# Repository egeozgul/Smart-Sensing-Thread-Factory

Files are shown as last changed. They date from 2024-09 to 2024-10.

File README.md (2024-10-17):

# Smart-Sensing-Thread-Factory

<p align="center">
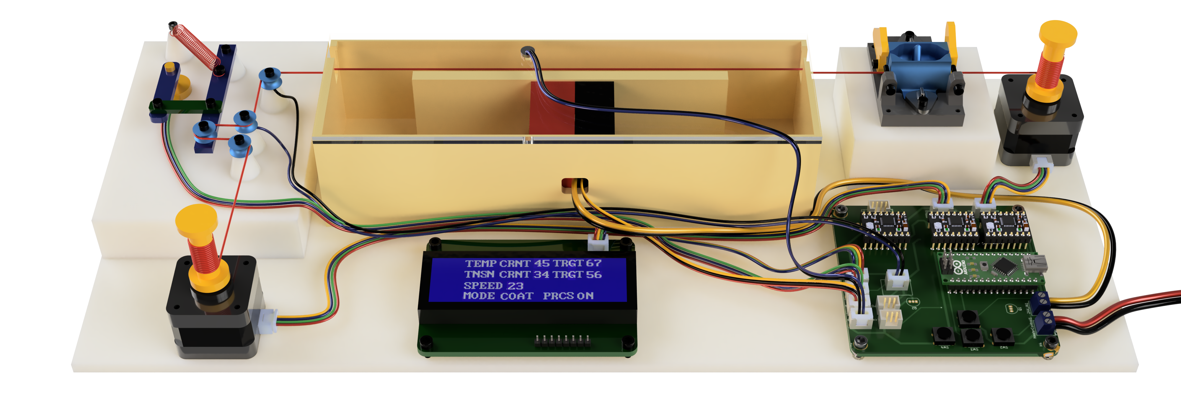
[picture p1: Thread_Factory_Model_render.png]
  
</p>

## Overview

This is a device built for Tufts NanoLab lab to assist the sensor development and wearable electronics research projects. This device automates the smart thread sensor production process using a combination of sensors and actuators.
This project is published at MDPI: [Publication Link](https://www.mdpi.com/2072-666X/15/10/1239) 

## Contents

- **PCB_productionFiles**: This folder contains all the necessary PCB design files required for creating the electronic boards that drive the system. The PCBs connect the microcontroller to the sensors and motors, enabling accurate monitoring and control.
  
- **cartridgeDesignFiles**: Inside this folder, you will find the 3D printable designs for various mechanical components, particularly the thread cartridge system. These parts can be printed using a 3D printer and are crucial for holding and guiding the thread during production.

- **firmwareSourceCode**: This directory includes the firmware for the microcontroller, which handles the overall operation of the system. The firmware reads sensor data, controls the stepper motors, adjusts system settings via a user interface, and maintains optimal conditions using PID control.

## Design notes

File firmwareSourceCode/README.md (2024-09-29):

# Driver for Smart Sensing Thread Factory

## Overview

This project is an Arduino-based system that integrates multiple sensors, stepper motors, and a heating element. It monitors temperature, tension, and conductivity using sensors and provides control mechanisms through stepper motors and a heating element. A PID controller is implemented for precise tension regulation, and real-time data is displayed on an LCD. User inputs allow dynamic adjustment of system parameters.

### Key Features:
- **Temperature Monitoring & Control**: Uses a thermistor to measure temperature and adjust a heater to maintain a target temperature.
- **Stepper Motor Control**: Drives three stepper motors with adjustable speed and direction to manage processes like ink feeding and tension control.
- **PID Control**: Ensures the tension rate is maintained within the desired range using feedback loops.
- **LCD Display**: Real-time display of key system parameters like temperature, tension, conductivity, and motor speed.
- **Button Inputs**: Four buttons allow users to adjust system settings, start/stop processes, and initiate thread tests.
- **Sensors**:
  - **Thermistor** for temperature.
  - **Tension Sensor** for tension measurement.
  - **Conductivity Sensor** for measuring conductivity.

## Hardware Components

1. **Arduino Board** (e.g., Arduino Uno)
2. **LCD Display**: I2C 20x4 display
3. **Thermistor**: For temperature sensing
4. **Conductivity Sensor**: To measure conductivity
5. **Tension Sensor**: To measure the tension rate
6. **Stepper Motors**: To control the mechanical processes (3 stepper motors)
7. **Buttons**: Four buttons for input control
8. **Heater**: To adjust and maintain temperature
9. **Fan**: To assist in cooling (optional)
10. **Wiring and Power Supplies**

### Pin Configuration

| Component | Pin Number |
|---|---|
| **Thermistor Pin** | A6 |
| **Fan Pin** | 6 |
| **Conductivity Sensor Pin**| A2 |
| **Tension Sensor Pin** | A3 |
| **Heater Pin** | 9 |
| **Stepper Motor A** | Dir: 2, Step: 3 |
| **Stepper Motor B** | Dir: 7, Step: 8 |
| **Pump Motor** | Dir: 10, Step: 11 |
| **LCD I2C Address** | 0x27 |

## Software Setup

### Requirements

- **Arduino IDE** (Download from [Arduino](https://www.arduino.cc/en/software))
- **Libraries**: 
  - `Wire.h`
  - `LiquidCrystal_I2C.h`

### Installing Libraries

1. Open the Arduino IDE.
2. Navigate to `Sketch > Include Library > Manage Libraries...`.
3. Search for **LiquidCrystal_I2C** in the Library Manager.
4. Install the **LiquidCrystal_I2C** library.

### Code Compilation and Upload

1. **Open the Code**:
   - Copy the provided Arduino code into a new sketch in the Arduino IDE.

2. **Select Your Arduino Board**:
   - Go to `Tools > Board` and select your Arduino model (e.g., Arduino Uno).

3. **Select the Correct Port**:
   - Go to `Tools > Port` and select the port your Arduino is connected to.

4. **Verify and Upload**:
   - Click the checkmark button (`Verify`) to compile the code.
   - Click the arrow button (`Upload`) to upload the compiled code to your Arduino.

5. **Connect the Components**:
   - Wire the thermistor, tension sensor, conductivity sensor, stepper motors, heater, and LCD according to the pin configuration above.

### Usage Instructions

- **Adjust Parameters**: Use the buttons to adjust temperature, motor speed, and tension rate as needed.
- **Start/Stop Processes**: Use the buttons to start/stop coating processes and initiate thread tests.
- **Monitor the LCD**: View real-time sensor readings, including temperature, tension rate, conductivity, and motor speed on the LCD display.
  
### Button Controls:

| Button | Function |
|---|---|
| **Up** | Navigate up in the menu |
| **Down** | Navigate down in the menu |
| **Left** | Decrease the selected parameter |
| **Right**| Increase the selected parameter |

### LCD Display Output:
- **Temperature**: Current temperature and target temperature
- **Conductivity**: Current conductivity value
- **Tension Rate**: Current and desired tension rate
- **Motor Speed**: Speed of the stepper motors

## Serial Monitoring

To monitor data and debug via the Serial Monitor:
1. Open **Serial Monitor** from `Tools > Serial Monitor` in the Arduino IDE.
2. Set the baud rate to **115200** to match the code.

The serial monitor will display:
- Stepper motor positions
- Tension rate and conductivity
- Test cycle results during thread tests

## Troubleshooting

- **No LCD Output**: Ensure the LCD is properly connected to the correct I2C address (`0x27`), and the contrast is adjusted.
- **Stepper Motors Not Running**: Check the wiring and verify that the stepper motors are connected to the correct pins.
- **Temperature Control Issues**: Ensure the thermistor is wired correctly and is within the operational range.
- **Buttons Not Responding**: Check the debouncing logic and verify correct pin connections.

## License

This project is open-source. Feel free to modify and distribute as needed.

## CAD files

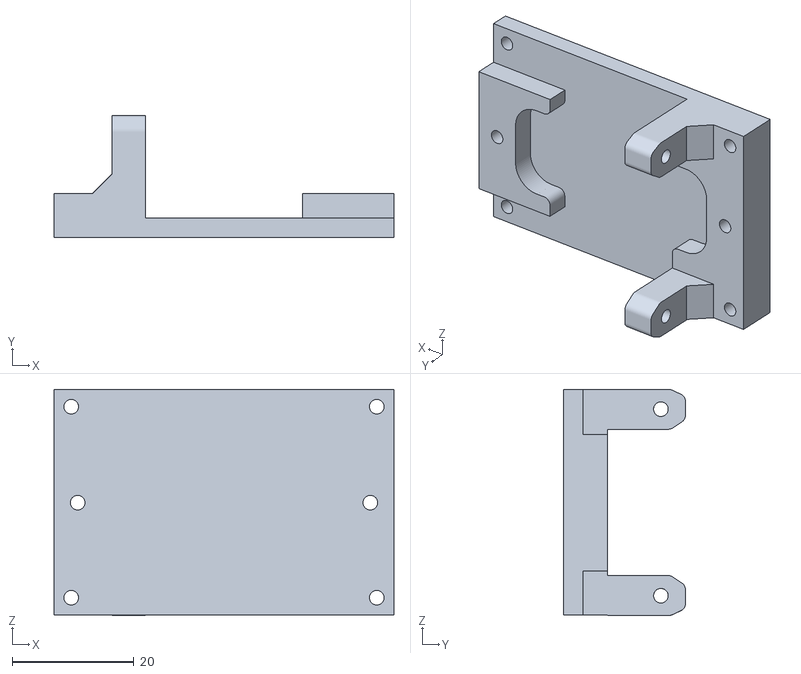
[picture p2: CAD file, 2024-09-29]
cartridgeDesignFiles/base.stl
55.8 x 20.0 x 37.1

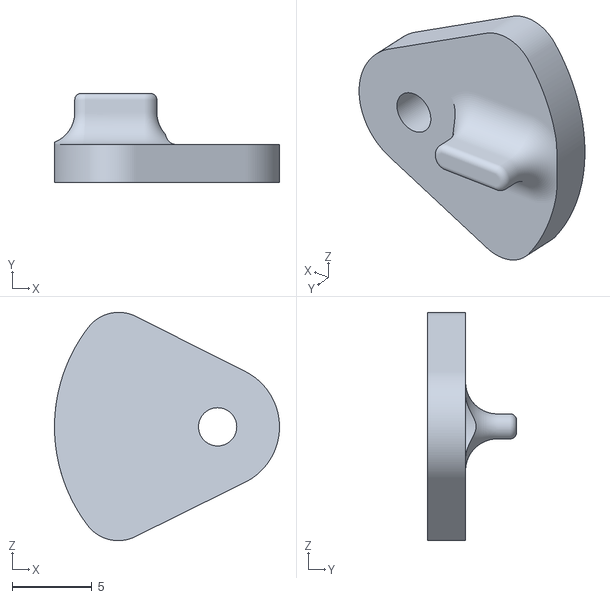
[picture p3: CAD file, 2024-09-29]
cartridgeDesignFiles/Clip.stl
14.1 x 5.60 x 14.3

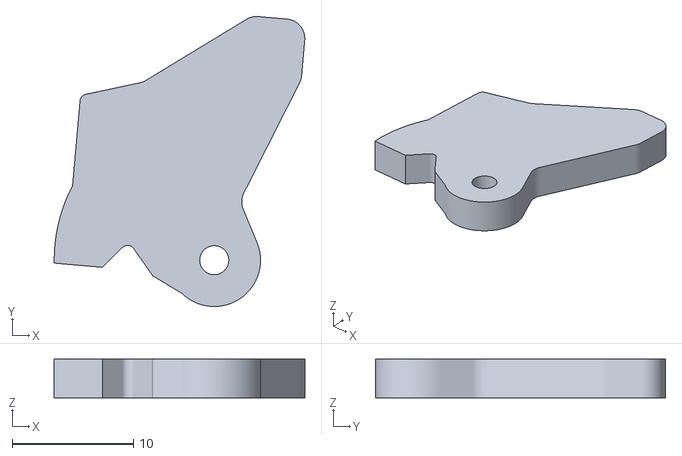
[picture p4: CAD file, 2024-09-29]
cartridgeDesignFiles/gate.stl
20.7 x 24.0 x 3.20

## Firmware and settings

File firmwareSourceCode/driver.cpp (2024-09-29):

#include <Wire.h> 
#include <LiquidCrystal_I2C.h>

LiquidCrystal_I2C lcd(0x27, 20, 4);  // LCD setup for 16 chars, 2 lines

#define thermistorPin A6
#define fanPin 6
#define conductivitySensorPin A2 
#define tensionSensorPin A3
#define heaterPin 9

// Speed calculation variable
float Speed = 10000.0f / 6000.0f;

// Function to convert sensor value to temperature
float convertToTemp(float Vo) {
  int ThermistorPin = 0;
  float R1 = 10000;
  float logR2, R2, T;
  float c1 = 1.009249522e-03, c2 = 2.378405444e-04, c3 = 2.019202697e-07;

  R2 = R1 * (1023.0 / Vo - 1.0);
  logR2 = log(R2);
  T = (1.0 / (c1 + c2 * logR2 + c3 * logR2 * logR2 * logR2)) - 273.15;

  return T;
}

// Buffer for moving average temperature calculation
float tempBuffer[30];

// Function to calculate moving average
float movingAverage(float *tempBuffer) {
  float sum = 0;
  for (int i = 0; i < 30; i++) {
    sum += tempBuffer[i];
  }
  return sum / 30.0f;
}

int index = 0;
void insertData(float newData) {
  tempBuffer[index] = newData;
  index = (index + 1) % 30;
}

int heaterValue = 0;

#define dirPin 2
#define stepPin 3
#define dirPinB 7
#define stepPinB 8
#define pumpDirPin 10
#define pumpStepPin 11

#define stepsPerRevolution 200

int stepperA_state = LOW;
int stepperB_state = LOW;
int stepperC_state = LOW;

// Stepper motor functions
void stepperStepA() {
  stepperA_state = !stepperA_state;
  digitalWrite(stepPin, stepperA_state);
}

void stepperStepB() {
  stepperB_state = !stepperB_state;
  digitalWrite(stepPinB, stepperB_state);
}

void stepperStepC() {
  stepperC_state = !stepperC_state;
  digitalWrite(pumpStepPin, stepperC_state);
}

// Setup for timer interrupts
void interruptSetup() {
  cli();  // Disable interrupts

  TCCR1A = 0;
  TCCR1B = 0;
  TCCR1B |= B00000100;  // Set prescaler to 256
  TIMSK1 |= B00000010;  // Enable compare match A
  OCR1A = 5;  // Set compare register A value

  sei();  // Enable interrupts
}

long int timerPeriod = 80;

int counterA = 0;
int counterB = 0;
int counterC = 0;

long int posA = 0;
long int posB = 0;
long int posC = 0;
int motorDirB = 1;

int enableMotorA = 0;
int enableMotorB = 0;
int enableMotorC = 0;

volatile int counterALimit = 30;
volatile int counterBLimit = 30;
volatile int counterCLimit = 2;

ISR(TIMER1_COMPA_vect) {
  TCNT1 = 0;  // Reset timer

  counterA++;
  counterB++;
  counterC++;

  if (counterA >= counterALimit && enableMotorA == 1) {
    counterA = 0;
    stepperStepA();  
    posA++;
  }

  if (counterB >= counterBLimit && enableMotorB == 1) {
    counterB = 0;
    stepperStepB();

    if (motorDirB == 1) {
      digitalWrite(dirPinB, LOW);
    } else {
      digitalWrite(dirPinB, HIGH);
    }
    posB += motorDirB;
  }

  if (counterC >= counterCLimit && enableMotorC == 1) {
    counterC = 0;
    stepperStepC();
    posC++;
  }

  static int cc = 0;
  int dutyCycle = heaterValue;
  if (cc == 0) digitalWrite(heaterPin, HIGH);
  if (cc == dutyCycle) digitalWrite(heaterPin, LOW); 
  cc++;
  if (cc >= 10) cc = 0;
}

void setup() {
  // Set pin modes for stepper motors and peripherals
  pinMode(stepPin, OUTPUT);
  pinMode(dirPin, OUTPUT);
  pinMode(stepPinB, OUTPUT);
  pinMode(dirPinB, OUTPUT);
  pinMode(pumpStepPin, OUTPUT);
  pinMode(pumpDirPin, OUTPUT);
  
  digitalWrite(dirPinB, LOW);
  digitalWrite(dirPin, HIGH);
  digitalWrite(pumpDirPin, LOW);
  
  interruptSetup();  // Set up interrupts

  lcd.init();  // Initialize LCD
  lcd.backlight();  // Turn on LCD backlight
  
  pinMode(13, OUTPUT);
  pinMode(fanPin, OUTPUT);
  pinMode(heaterPin, OUTPUT);
  analogWrite(fanPin, 255);  // Set fan speed

  Serial.begin(115200);

  pinMode(1, INPUT_PULLUP);
  pinMode(A0, INPUT_PULLUP);
  pinMode(0, INPUT_PULLUP);
  pinMode(A1, INPUT_PULLUP);

  counterBLimit = 10000.0f / Speed;

  int stepperEnablePin = 4;
  pinMode(stepperEnablePin, OUTPUT);
  digitalWrite(stepperEnablePin, HIGH);
  delay(1000);
  digitalWrite(stepperEnablePin, LOW);
}

// PID control variables
static float P = 0;
static float I = 0;
static float D = 0;
static float kP = 250.0;
static float kI = 0.0001f;
static float kD = 0;
static float totalError = 0;

int ProcessStarted = false;
int ThreadTestStarted_A = false;
int ThreadTestStarted_B = false;

float inkFeedrate = 10;
float currentTemp = 0;
int desiredTensionRate = 850;
float desiredTemp  = 55;

static int selection = 0;
int nSelections = 8;

// Button functions
void buttonRight() {
  if (selection == 0) desiredTemp++;
  if (selection == 1) Speed += 10;
  if (selection == 2) desiredTensionRate += 5;
  if (selection == 4) inkFeedrate += 10;
  if (selection == 5) ProcessStarted = !ProcessStarted;
  if (selection == 6) ThreadTestStarted_A = !ThreadTestStarted_A;
  if (selection == 7) ThreadTestStarted_B = !ThreadTestStarted_B;

  counterBLimit = 10000.0f / Speed;
}

void buttonLeft() {
  if (selection == 0) desiredTemp--;
  if (selection == 1) Speed -= 10;
  if (selection == 2) desiredTensionRate -= 5;
  if (selection == 4) inkFeedrate -= 10;

  if (Speed < 5) Speed = 10;

  counterBLimit = 10000.0f / Speed;
}

void buttonUp() {
  selection = (selection + 1) % nSelections;
}

void buttonDown() {
  selection--;
  if (selection < 0) selection = nSelections - 1;
}

// Update the LCD with the current values
void updateLCD() {   
  lcd.setCursor(0, 0);
  lcd.print("tmp:");
  lcd.print((int)currentTemp);
  lcd.print("/");
  lcd.print((int)desiredTemp);
  
  lcd.setCursor(10, 0);
  lcd.print("Ink:");
  lcd.print(inkFeedrate);

  lcd.setCursor(0, 1);
  lcd.print("Con:");
  lcd.print(conductivity);

  lcd.setCursor(0, 2);
  lcd.print("Tension:");
  lcd.print((int)tensionRate);
  lcd.print("/");
  lcd.print((int)desiredTensionRate);

  lcd.setCursor(10, 1);
  lcd.print("Spd:");
  lcd.print(Speed);

  lcd.setCursor(0, 3);
  switch (selection) {
    case 0:
      lcd.print("Adjust temperature");  
      break;
    case 1:
      lcd.print("Adjust spool speed");
      break;
    case 2:
      lcd.print("Adjust tension");
      break;
    case 3:
      lcd.print("Manual pump control");
      break;
    case 4:
      lcd.print("Adjust pump rate");
      break;
    case 5:
      lcd.print(ProcessStarted ? "STOP COATING" : "START COATING");
      break;
    case 6:
      lcd.print(ThreadTestStarted_A ? "STOP THREAD TEST A" : "START THREAD TEST A");
      break;
    case 7:
      lcd.print(ThreadTestStarted_B ? "STOP THREAD TEST B" : "START THREAD TEST B");
      break;
  }
}

// PID control function for tension rate
void pid(int tensionRate) {
  float error = tensionRate - desiredTensionRate;
  float speedB = Speed;
  float speedA = speedB - kP * error;

  float result = 10000.0f / speedA;
  
  digitalWrite(dirPin, speedA >= 0 ? HIGH : LOW);

  counterALimit = abs(result);

  if (totalError > 0.30) totalError = 0.3;
  if (totalError < -0.30) totalError = -0.3;
}

void loop() {
  // Process control logic
  if (ProcessStarted) {
    enableMotorA = 1;
    enableMotorB = 1;
    digitalWrite(pumpDirPin, HIGH);
    
    if (inkFeedrate <= 5) {
      inkFeedrate = 5;
      counterCLimit = 1000000.0f / inkFeedrate;
      enableMotorC = 0;
    } else {
      counterCLimit = 1000000.0f / inkFeedrate;
      enableMotorC = 1;
    }
  } else if (ThreadTestStarted_A) {
    enableMotorA = 1;
    enableMotorB = 1;
    Speed = 5000;
    counterBLimit = 10000.0f / Speed; 
  } else if (ThreadTestStarted_B) {
    enableMotorA = 1;
    enableMotorB = 0;
  } else {
    enableMotorA = 0;
    enableMotorB = 0;
  }

  // Manual pump control
  if (digitalRead(1) == false && selection == 3) {
    digitalWrite(pumpDirPin, LOW);
    counterCLimit = 5;
    enableMotorC = 1;
  } else if (digitalRead(A0) == false && selection == 3) {
    digitalWrite(pumpDirPin, HIGH);
    counterCLimit = 5;
    enableMotorC = 1;
  } else {
    enableMotorC = ProcessStarted ? 1 : 0;
  }

  // Button handling
  int pins[4] = {0, A1, A0, 1};
  static long debouncingTimer[4] = {0, 0, 0, 0};
  static bool enable[4] = {1, 1, 1, 1};
  void (*buttonActions[4])() = {buttonUp, buttonDown, buttonRight, buttonLeft};
  
  for (int i = 0; i < 4; i++) {
    if (digitalRead(pins[i]) == false && enable[i] == 1) {
      debouncingTimer[i] = millis();
      enable[i] = 0;
      buttonActions[i]();
    }
    if (enable[i] == 0 && millis() > debouncingTimer[i] + 250) {
      enable[i] = 1;
    }
  }

  // Tension sensor reading
  tensionRate = analogRead(tensionSensorPin);
  
  // Conductivity sensor reading
  conductivity = analogRead(conductivitySensorPin);

  // Apply PID control for tension rate
  pid(tensionRate);

  // Heater control
  int rawTemp = analogRead(thermistorPin);
  insertData(rawTemp);
  rawTemp = movingAverage(tempBuffer);
  currentTemp = convertToTemp(rawTemp);

  heaterValue = (currentTemp < desiredTemp) ? 10 : 0;

  // Update the LCD periodically
  static unsigned long int LCD_update_counterStartTime = millis();
  if (millis() - LCD_update_counterStartTime > 50) {
    updateLCD();
    LCD_update_counterStartTime = millis();
  }

  // USB Serial logging
  static unsigned long int Log_counterStartTime = millis();
  if (millis() - Log_counterStartTime > 200) {
    if (ThreadTestStarted_A) {
      Serial.print((long int)posB);
      Serial.print(" ");
      Serial.println((int)conductivity);
    }

    if (ThreadTestStarted_B) {
      Serial.print((int)tensionRate);
      Serial.print(" ");
      Serial.print((int)conductivity);
      Serial.print(" ");
      Serial.println(counter_);
    }
    Log_counterStartTime = millis();
  }

  // Thread Test logic
  static int n_cycles = 1000;
  static bool countingUp = false;
  static int counter_period_millis = 25;
  static long int counter_counterStartTime = millis();

  if (millis() - counter_counterStartTime > counter_period_millis) {
    if (ThreadTestStarted_B) {
      if (countingUp) {
        if (tensionRate < 800) desiredTensionRate += 3;
        if (tensionRate > 800) {
          countingUp = false;
          counter_++;
        }
      } else {
        if (tensionRate > 450) desiredTensionRate -= 3;
        if (tensionRate < 450) countingUp = true;
      }
    }
    counter_counterStartTime = millis();
  }
  
  if (counter_ >= n_cycles) {
    ThreadTestStarted_B = false;
    Serial.println("CycleTestEnd");
  }
}
